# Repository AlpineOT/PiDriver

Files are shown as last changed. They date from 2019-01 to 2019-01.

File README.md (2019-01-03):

# PiDriver
KiCad Raspberry Pi Solenoid Driver Board

Alpine designed this RPi add-on board to drive solenoids for test automation; however, it's a generic 10-channel MOSFET board that could also be used to drive relays, LEDS, DC motors, etc.

## Features

* Controls up to 10 solenoids (though the number that can be simultaneously activated will depend upon the solenoid and capacity of your power supply)
* 2 of the 10 channels have PWM capability
* Designed for a 9-24V power input and, thus, 9-24V solenoids
* On-board flyback protection for inductive loads
* Designed for fast solenoid switching

## Fabrication

See the README_FAB.txt for notes on how the board is fabricated. Fabrication packages can be found on the [Releases](https://github.com/AlpineOT/PiDriver/releases) tab in the Github repo.

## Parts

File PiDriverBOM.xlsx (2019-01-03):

PCBA Name: |  | PiDriver
PCBA Revision: |  | 2
Item # | Quantity | Reference Designator | Manufacturer | Manufacturer Part Number | Description/Value | Vendor | Vendor Part Number | Notes
1 | 1 | C5 | KEMET | T491X107K025AT | CAP TANT 100UF 25V 10% 2917 | Digikey | 399-8410-1-ND
2 | 1 | C6 | DNP | DNP | DNP | DNP | DNP | DNP
3 | 10 | D1, D2, D3, D4, D9, D10, D11, D12, D17, D18 | Micro Commercial Co | 1N4448W-TP | DIODE GEN PURP 75V 250MA SOD123 | Digikey | 1N4448WTPMSCT-ND
4 | 10 | D5, D6, D7, D8, D13, D14, D15, D16, D19, D20 | Panasonic Electronic Components | DZ2W39000L | DIODE ZENER 39V 1W MINI2 | Digikey | DZ2W39000LCT-ND
5 | 1 | J0 | Harwin Inc. | M20-7832046 | DIL VERTICAL PC TAIL SOCKET ASSY | Digikey | 952-2150-ND
6 | 11 | J1, J2, J3, J4, J5, J6, J7, J8, J9, J10, J12 | Phoenix Contact | 1725656 | CONN TERM BLOCK 2.54MM 2POS | Digikey | 277-1273-ND
7 | 1 | J11 | CUI Inc. | PJ-063AH | CONN PWR JACK 2X5.5MM SOLDER | Digikey | CP-063AH-ND
8 | 10 | Q1, Q2, Q3, Q4, Q5, Q6, Q7, Q8, Q9, Q10 | Infineon Technologies | IRLU024NPBF | MOSFET N-CH 55V 17A I-PAK | Digikey | IRLU024NPBF-ND
9 | 10 | R1, R2, R3, R4, R5, R6, R7, R8, R9, R10 | Yageo | RC0805FR-0747KL | RES SMD 47K OHM 1% 1/8W 0805 | Digikey | 311-47.0KCRCT-ND

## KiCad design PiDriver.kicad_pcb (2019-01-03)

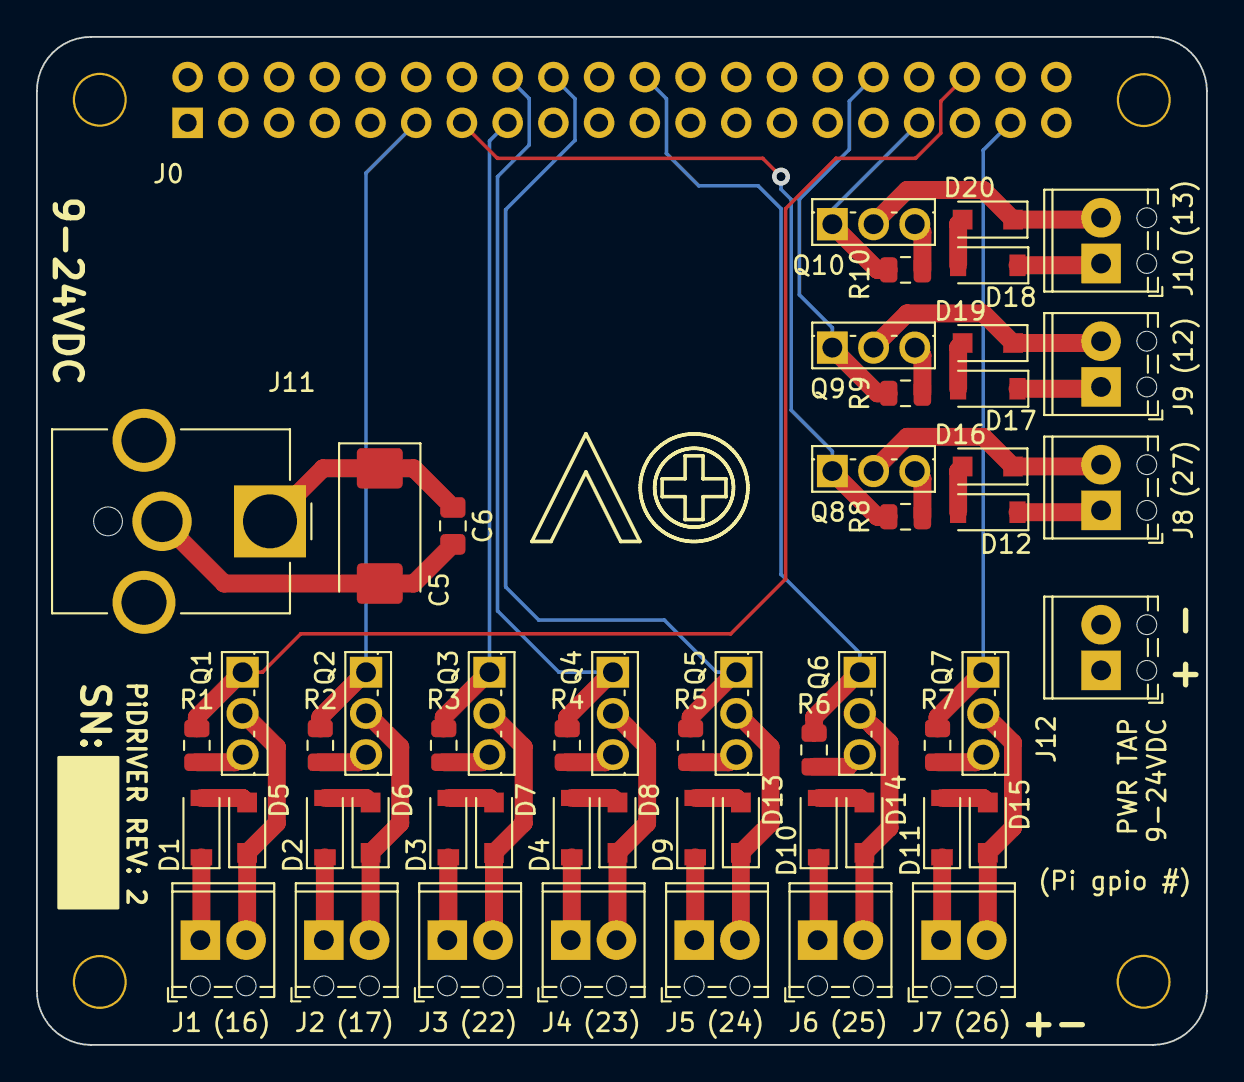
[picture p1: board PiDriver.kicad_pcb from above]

Board: 4 copper layers, 65.0 x 56.0 mm, 60 parts (1 on the bottom side), 32 nets.

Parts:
C5: 100uF; CP_EIA-7343-43_Kemet-X_Pad2.25x2.55mm_HandSolder
C6: DNP; C_0805_2012Metric_Pad1.15x1.40mm_HandSolder
D1, D2, D3, D4, D9, D10, D11, D12, D17, D18: 1N4448W; D_SOD-123
D5, D6, D7, D8, D13, D14, D15, D16, D19, D20: DZ2W39000L; D_SOD-123F
J0: Raspberry_Pi_2_3; PinSocket_2x20_P2.54mm_Vertical
J1, J2, J3, J4, J5, J6, J7, J8, J9, J10, J12: Screw_Terminal_01x02; TerminalBlock_Phoenix_MPT-0,5-2-2.54_1x02_P2.54mm_Horizontal
J11: Jack-DC; BarrelJack_CUI_PJ-063AH_Horizontal_CircularHoles
LOGO1: AlpineLogo
MH1, MH2, MH3, MH4: MountingHole; NPTH_3mm_ID
Q1, Q2, Q3, Q4, Q5, Q6, Q7, Q8, Q9, Q10: IRLU024NPBF; TO-251-3_Vertical
R1, R2, R3, R4, R5, R6, R7, R8, R9, R10: 47K; R_0805_2012Metric

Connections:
/DRIVER_1: J0.36, Q1.1, R1.1
/DRIVER_2: J0.11, Q2.1, R2.1
/DRIVER_3: J0.15, Q3.1, R3.1
/DRIVER_4: J0.16, Q4.1, R4.1
/DRIVER_5: J0.18, Q5.1, R5.1
/DRIVER_6: J0.22, Q6.1, R6.1
/DRIVER_7: J0.37, Q7.1, R7.1
/DRIVER_8: J0.13, Q8.1, R8.1
/DRIVER_9: J0.32, Q9.1, R9.1
/DRIVER_10: J0.33, Q10.1, R10.1
GND: C5.2, C6.2, J0.6, J0.9, J0.14, J0.20, J0.25, J0.30, J0.34, J0.39, J11.2, J12.2, Q1.3, Q2.3, Q3.3, Q4.3, Q5.3, Q6.3, Q7.3, Q8.3, Q9.3, Q10.3, R1.2, R2.2, R3.2, R4.2, R5.2, R6.2, R7.2, R8.2, R9.2, R10.2
unnamed: D1.2, D5.2
unnamed: D2.2, D6.2
unnamed: D3.2, D7.2
unnamed: D4.2, D8.2
unnamed: D5.1, J1.2, Q1.2
unnamed: D6.1, J2.2, Q2.2
unnamed: D7.1, J3.2, Q3.2
unnamed: D8.1, J4.2, Q4.2
unnamed: D10.2, D14.2
unnamed: D11.2, D15.2
unnamed: D12.2, D16.2
unnamed: D13.1, J5.2, Q5.2
unnamed: D9.2, D13.2
unnamed: D14.1, J6.2, Q6.2
unnamed: D15.1, J7.2, Q7.2
unnamed: D16.1, J8.2, Q8.2
unnamed: D17.2, D19.2
unnamed: D18.2, D20.2
unnamed: D19.1, J9.2, Q9.2
unnamed: D20.1, J10.2, Q10.2
VCC: C5.1, C6.1, D1.1, D2.1, D3.1, D4.1, D9.1, D10.1, D11.1, D12.1, D17.1, D18.1, J1.1, J2.1, J3.1, J4.1, J5.1, J6.1, J7.1, J8.1, J9.1, J10.1, J11.1, J12.1

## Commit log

2018-08-24 First board revision
    [PiDriver.kicad_pcb, PiDriver.sch, PiDriver_Drivers.sch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]
2019-01-03 Minor README.md correction
    Removed mention of powering the Raspberry Pi since that's been removed for thermal reasons.
2019-01-03 Update fab notes to allow vendor to choose solder mask finish.
    Our vendor can't do matte white finish. Updating fab notes to indicate
    our preference of matte, but also allow semi-gloss and gloss.
2019-01-03 Removed 5V linear regulator because it generated too much heat.
    The 5V linear regulator generated a ton of heat right above the Pi
    processor, which caused it to thermally-overload and reset. So, we won't
    try to power the Pi from this board for now. In the future, we could use
    a more efficient switching supply that wouldn't generate as much heat.
    But, we can separately power the Pi via USB for now.
    [PiDriver.kicad_pcb, PiDriver.sch, PiDriver_Drivers.sch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]
2019-01-03 Tweaked silkscreen for readability
    [PiDriver.kicad_pcb]
2019-01-03 Added BOM and updated readme.
    [PiDriverBOM.xlsx]

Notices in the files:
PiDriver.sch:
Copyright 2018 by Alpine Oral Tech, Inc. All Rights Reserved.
